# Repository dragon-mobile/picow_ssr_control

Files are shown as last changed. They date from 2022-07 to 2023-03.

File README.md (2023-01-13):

# picow_ssr_control

<br/>



<br/>

The Raspberry Pi Pico W Solid State Relay Controller is primarily meant to be
used with an open hardware solid state relay PCBs that is being co-developed
alongside this project as part of my Dragon Mobile GitHub organization to make
useful hardware with associated firmware and software for the tiny home, van
life and maker communities.

## Visual 3D examples

Top view<br/>
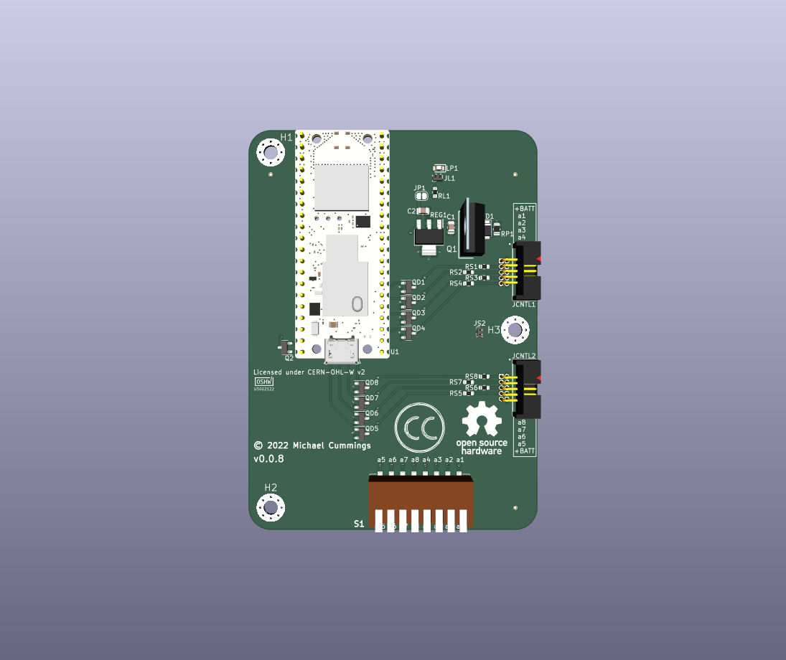
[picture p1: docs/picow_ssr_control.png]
Top view 3D rendering of the circuit board in FreeCAD Circuit board top view
<br/>
Bottom view<br/>
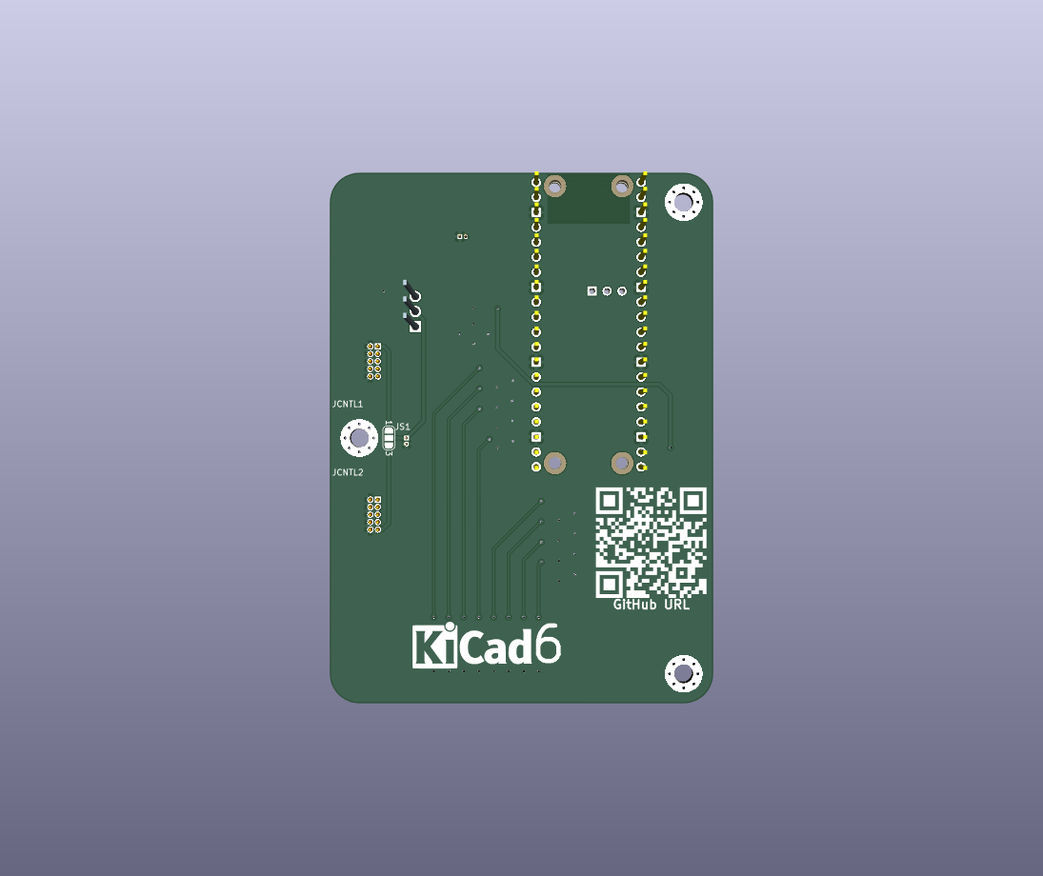
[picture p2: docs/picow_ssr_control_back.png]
Bottom view 3D rendering of the circuit board in FreeCAD Circuit board bottom view
<br/>

## Description

The board consist of four main electronic sections: Power In / Control Out,
Power Management / Regulation, Manual Control,
and the PicoW Control / Drivers.
There is one mechanical section as well: Mounting Holes.

## Contributing

Contributors are welcome.
Please note that this project has a [Contributor Covenant Code of Conduct].
By participating in this project you agree to abide by its terms.

All intentionally contributed hardware will be considered to be contributed
under the [CERN] license without any additional terms or conditions.

All intentionally contributed code will be considered to be contributed
under a [MIT] license without any additional terms or conditions.
Please include your information in a comment on all code files for the copyright
etc.

All intentionally contributed documentation, CAD files and libraries, footprints,
artwork or non-code text like this README etc. will be considered to be
contributed under the same [CC-BY-SA] license without any additional terms or
conditions.

Pull requests are always welcome. For major changes, please open an issue first
to discuss what you would like to change.
Please make sure to update or add tests as appropriate for all software changes.

## Licenses

GitHub<br/>

All hardware is licensed under the

  * [CERN] - CERN-OHL-W-2.0
  
You can find a copy of the CERN Open Hardware License - Weakly-reciprocal v2.0
in the [LICENSE-CERN-OHL-W-2] file and the how-to guide in the
[CERN-HOWTO_GUIDE] file.

All code is licensed under the

  * [MIT] - MIT License

You can find a copy of the license in the [LICENSE-MIT] file.

All documentation like this README is licensed under the Creative Commons
Attribution-ShareAlike 4.0 International License (CC-BY-SA).

All original CAD files and libraries, footprints, and artwork are also licensed
under the
Creative Commons Attribution-ShareAlike 4.0 International License (CC-BY-SA).
You can find a copy of the [CC-BY-SA] license in the [LICENSE-CC-BY-SA] file.

If after reading the above license files, how-tos, and related FAQs on the
linked license sites on how they apply to the project please either open an
issue or contact me (Michael Cummings) via my Github email and I will try
to guided you through my understanding of how it works.

[CC-BY-SA]: http://creativecommons.org/licenses/by-sa/4.0/
[CERN]: https://ohwr.org/project/cernohl/wikis/Documents/CERN-OHL-version-2
[CERN-HOWTO_GUIDE]: docs/cern_ohl_w_v2_howto.pdf
[Contributor Covenant Code of Conduct]: CODE_OF_CONDUCT.md 
[LICENSE-CC-BY-SA]: LICENSE-CC-BY-SA
[LICENSE-CERN-OHL-W-2]: CERN-OHL-W-2
[LICENSE-MIT]: LICENSE-MIT
[MIT]: https://opensource.org/licenses/MIT

<hr>
Copyright &copy; 2022-2023, Michael Cummings<br/>
<a rel="license" href="http://creativecommons.org/licenses/by-sa/4.0/">

</a>

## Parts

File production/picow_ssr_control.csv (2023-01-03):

Id | Designator | Package | Quantity | Designation | Supplier and ref
1 | REG1 | SOT230P700X180-4N | 1 | LM7805
2 | JS2,JL1 | PinHeader_1x02_P1.00mm_Vertical | 2 | Conn_01x02
3 | RS4,RS7,RS1,RS5,RS2,RL1,RS6,RS8,RS3 | R_0603_1608Metric | 9 | 270
4 | QD8,QD2,QD1,QD6,QD4,QD3,QD5,QD7 | SOT-23 | 8 | 2N7002K
5 | JCNTL2,JCNTL1 | SAMTEC_SHF-105-01-L-D-RA | 2 | SHF-105-01-L-D-RA
6 | Q2 | DMG2301L | 1 | DMG2301L
7 | C2 | C_0805_2012Metric | 1 | 100n
8 | S1 | 1938MS | 1 | 193-8MS
9 | RP1 | R_0805_2012Metric | 1 | 100k
10 | C1 | C_0805_2012Metric | 1 | 330n
11 | Q1 | TO254P469X1042X1967-3P | 1 | IRF4905PBF
12 | ZD1 | BZD27C10P-M3-08 | 1 | +10v Zener Diode
13 | LP1 | LEDC1608X80N | 1 | LTST-C190KGKT
14 | U1 | Raspberry_Pi_Pico_THT | 1 | RaspberryPi-PicoW

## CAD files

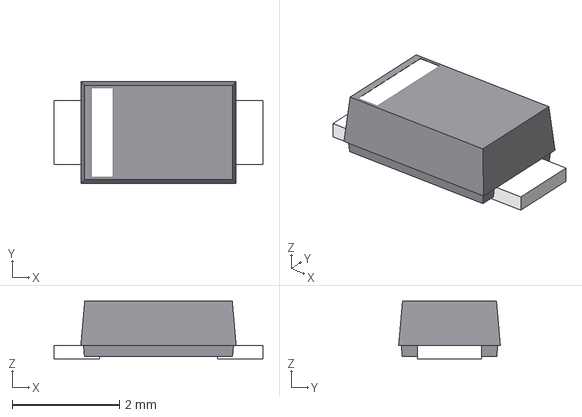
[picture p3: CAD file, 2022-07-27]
hardware/picow_ssr_control/3dmodels/BZD27C10P-M3-08.stp
3.90 x 1.90 x 1.08 mm

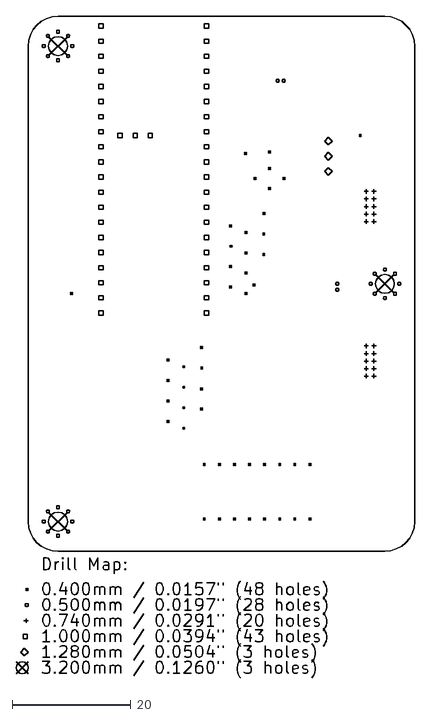
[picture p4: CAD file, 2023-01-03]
production/picow_ssr_control-PTH-drl_map.dxf
67.0 x 111.3

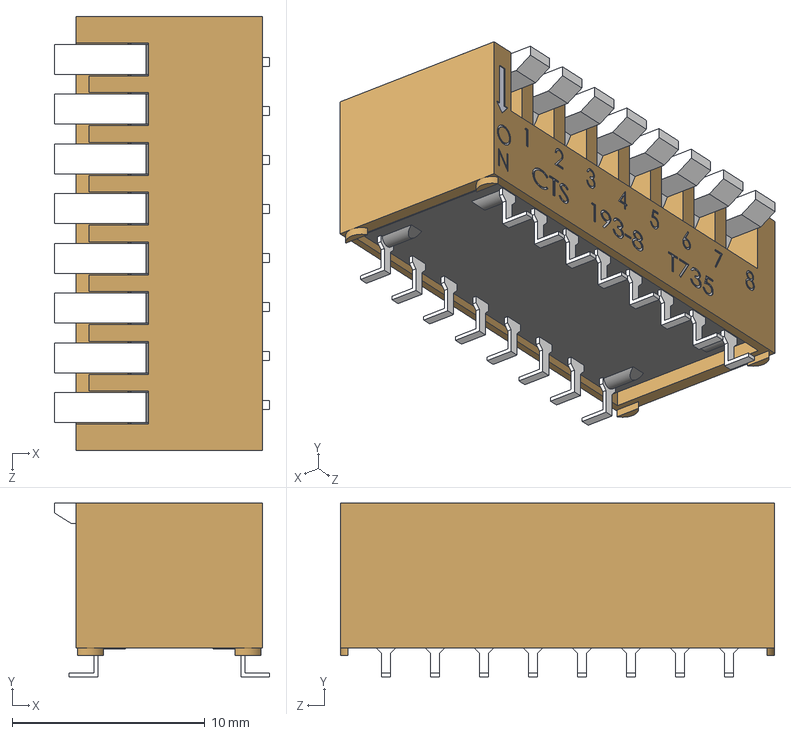
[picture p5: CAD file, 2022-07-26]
hardware/picow_ssr_control/3dmodels/193-8MS.STEP
11.2 x 9.02 x 22.5 mm
193-8 pole assembly

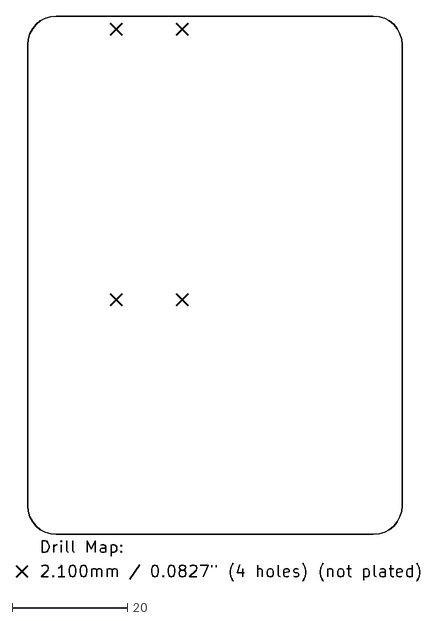
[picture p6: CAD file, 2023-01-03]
production/picow_ssr_control-NPTH-drl_map.dxf
70.1 x 98.1

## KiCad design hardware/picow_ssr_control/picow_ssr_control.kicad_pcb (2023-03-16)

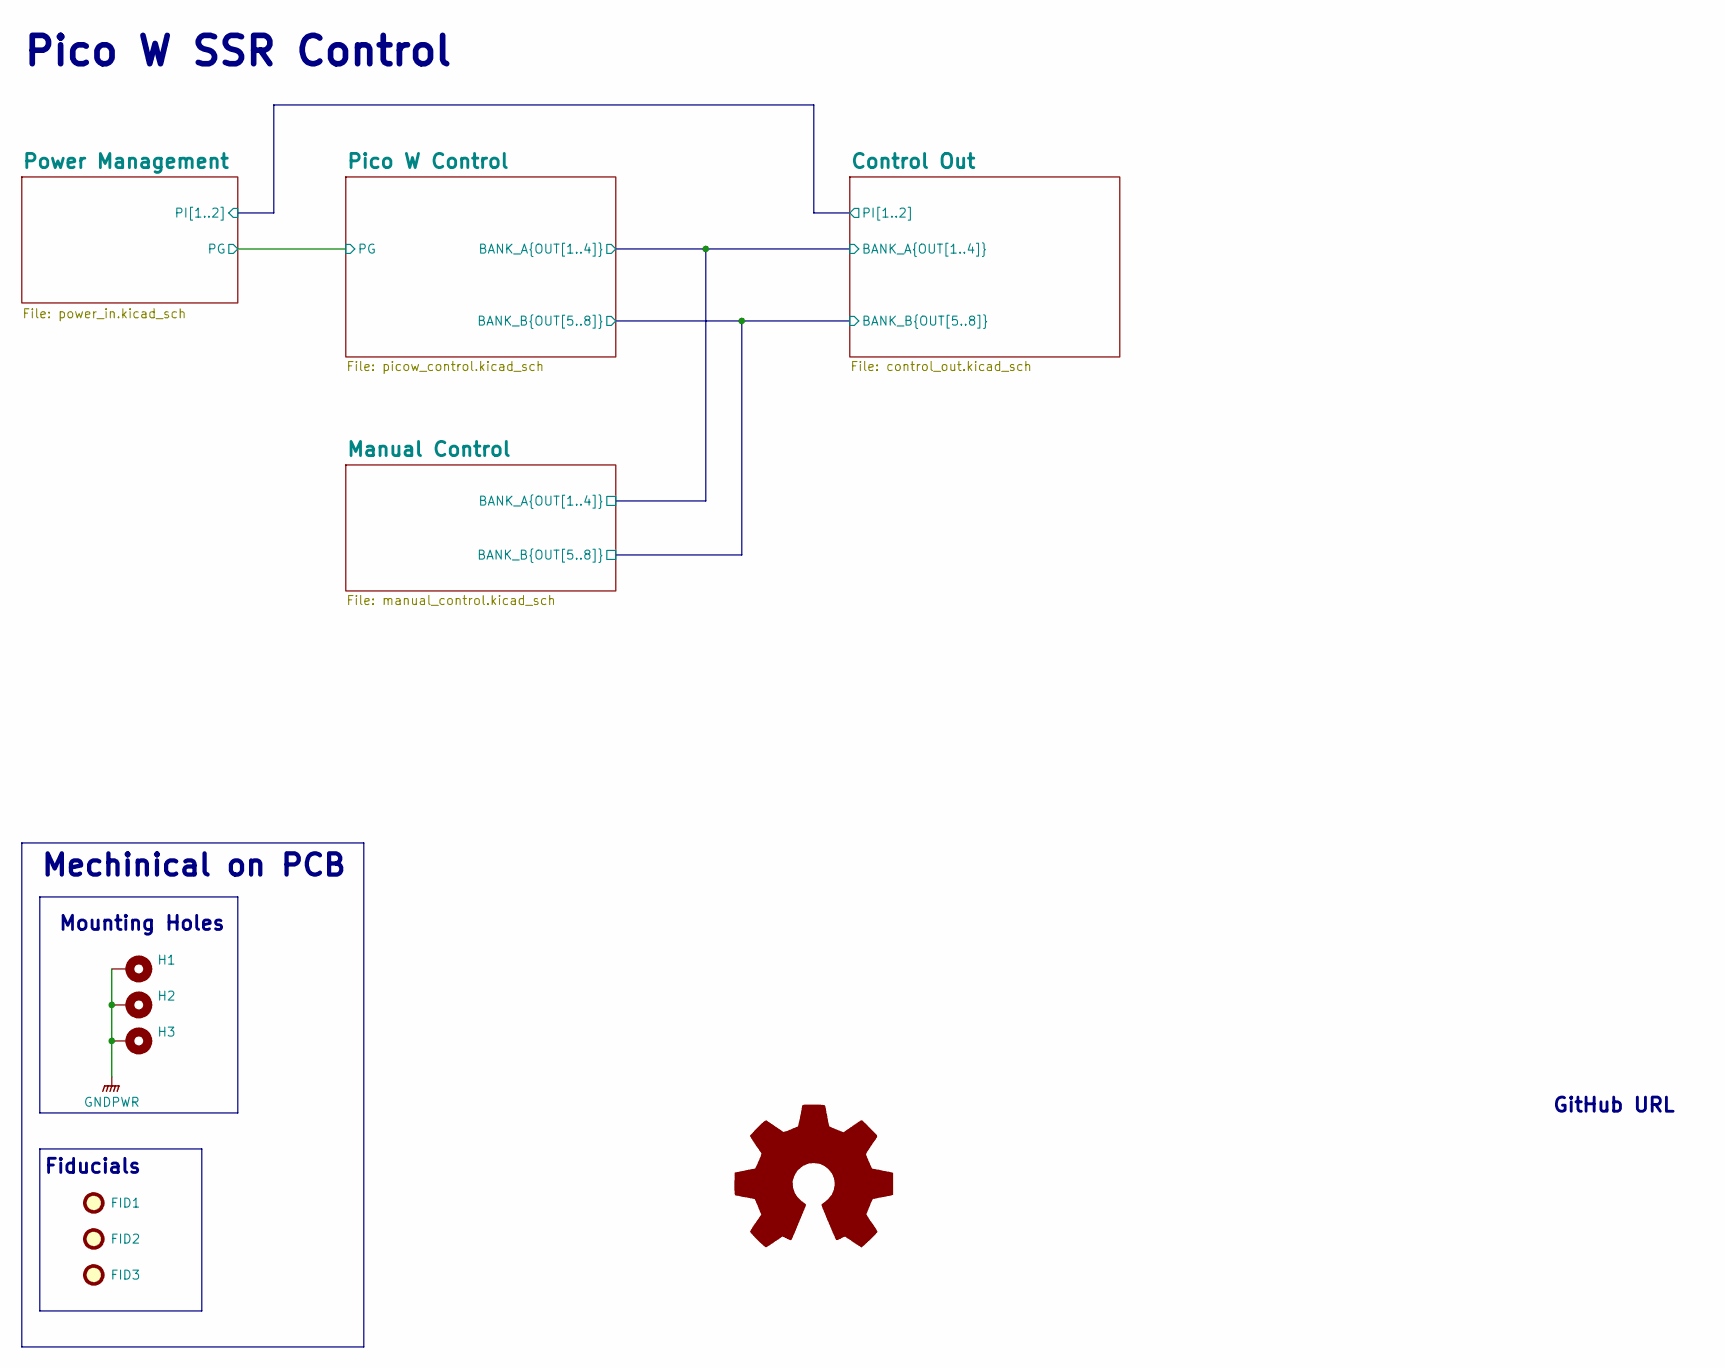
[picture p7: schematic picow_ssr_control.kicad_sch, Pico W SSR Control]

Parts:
FID1, FID2, FID3: Fiducial; Fiducial_0.5mm_Mask1mm
H1, H2, H3: MountingHole_Pad; MountingHole_3.2mm_M3_Pad_Via

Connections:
GNDPWR: H1.1, H2.1, H3.1; also elsewhere on the board

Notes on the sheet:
${TITLE}
Mounting Holes
GitHub URL
Mechinical on PCB
Fiducials

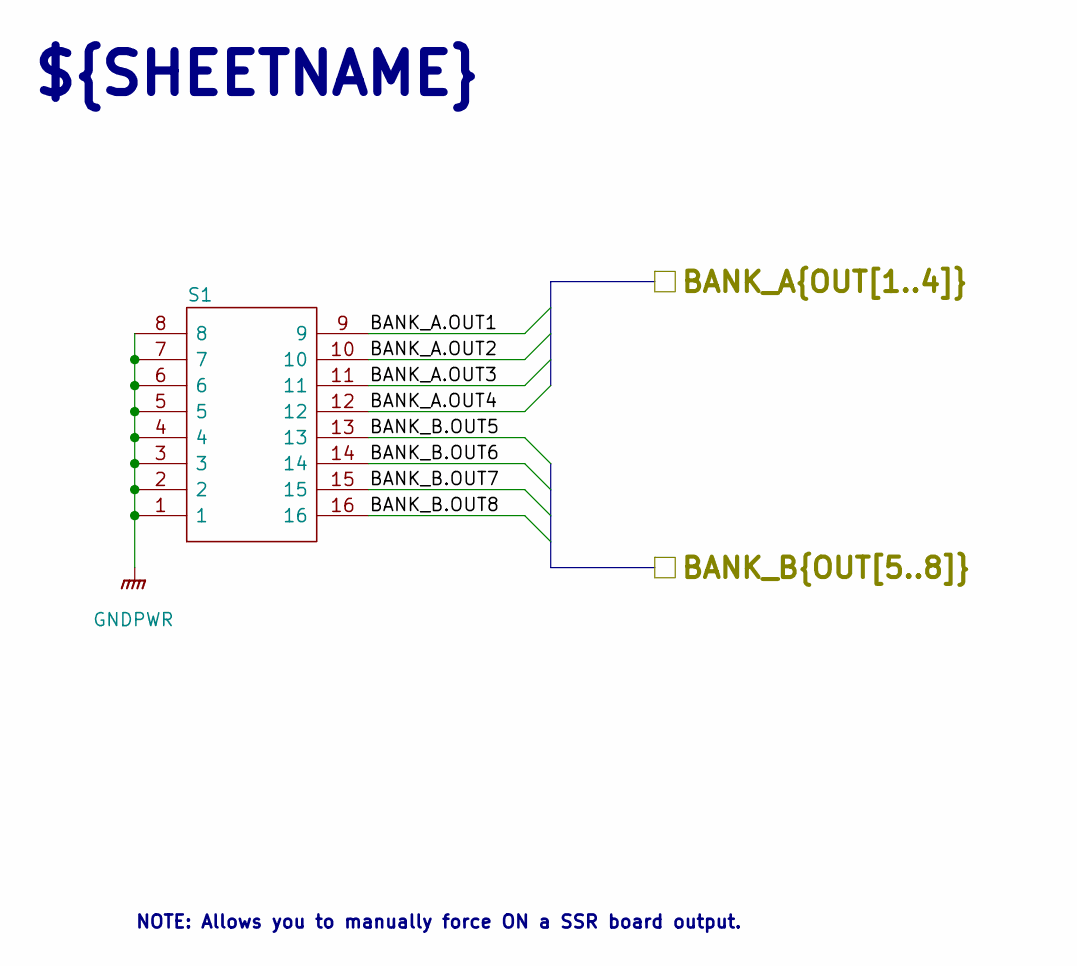
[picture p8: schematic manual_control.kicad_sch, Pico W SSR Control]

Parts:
S1: 193-8MS; 1938MS; Mouser Part Number 774-1938MS

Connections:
/Control Out/BANK_A.OUT1: S1.9; also elsewhere on the board
/Control Out/BANK_A.OUT2: S1.10; also elsewhere on the board
/Control Out/BANK_A.OUT3: S1.11; also elsewhere on the board
/Control Out/BANK_A.OUT4: S1.12; also elsewhere on the board
/Control Out/BANK_B.OUT5: S1.13; also elsewhere on the board
/Control Out/BANK_B.OUT6: S1.14; also elsewhere on the board
/Control Out/BANK_B.OUT7: S1.15; also elsewhere on the board
/Control Out/BANK_B.OUT8: S1.16; also elsewhere on the board
GNDPWR: S1.1, S1.2, S1.3, S1.4, S1.5, S1.6, S1.7, S1.8; also elsewhere on the board

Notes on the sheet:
${SHEETNAME}
NOTE: Allows you to manually force ON a SSR board output.

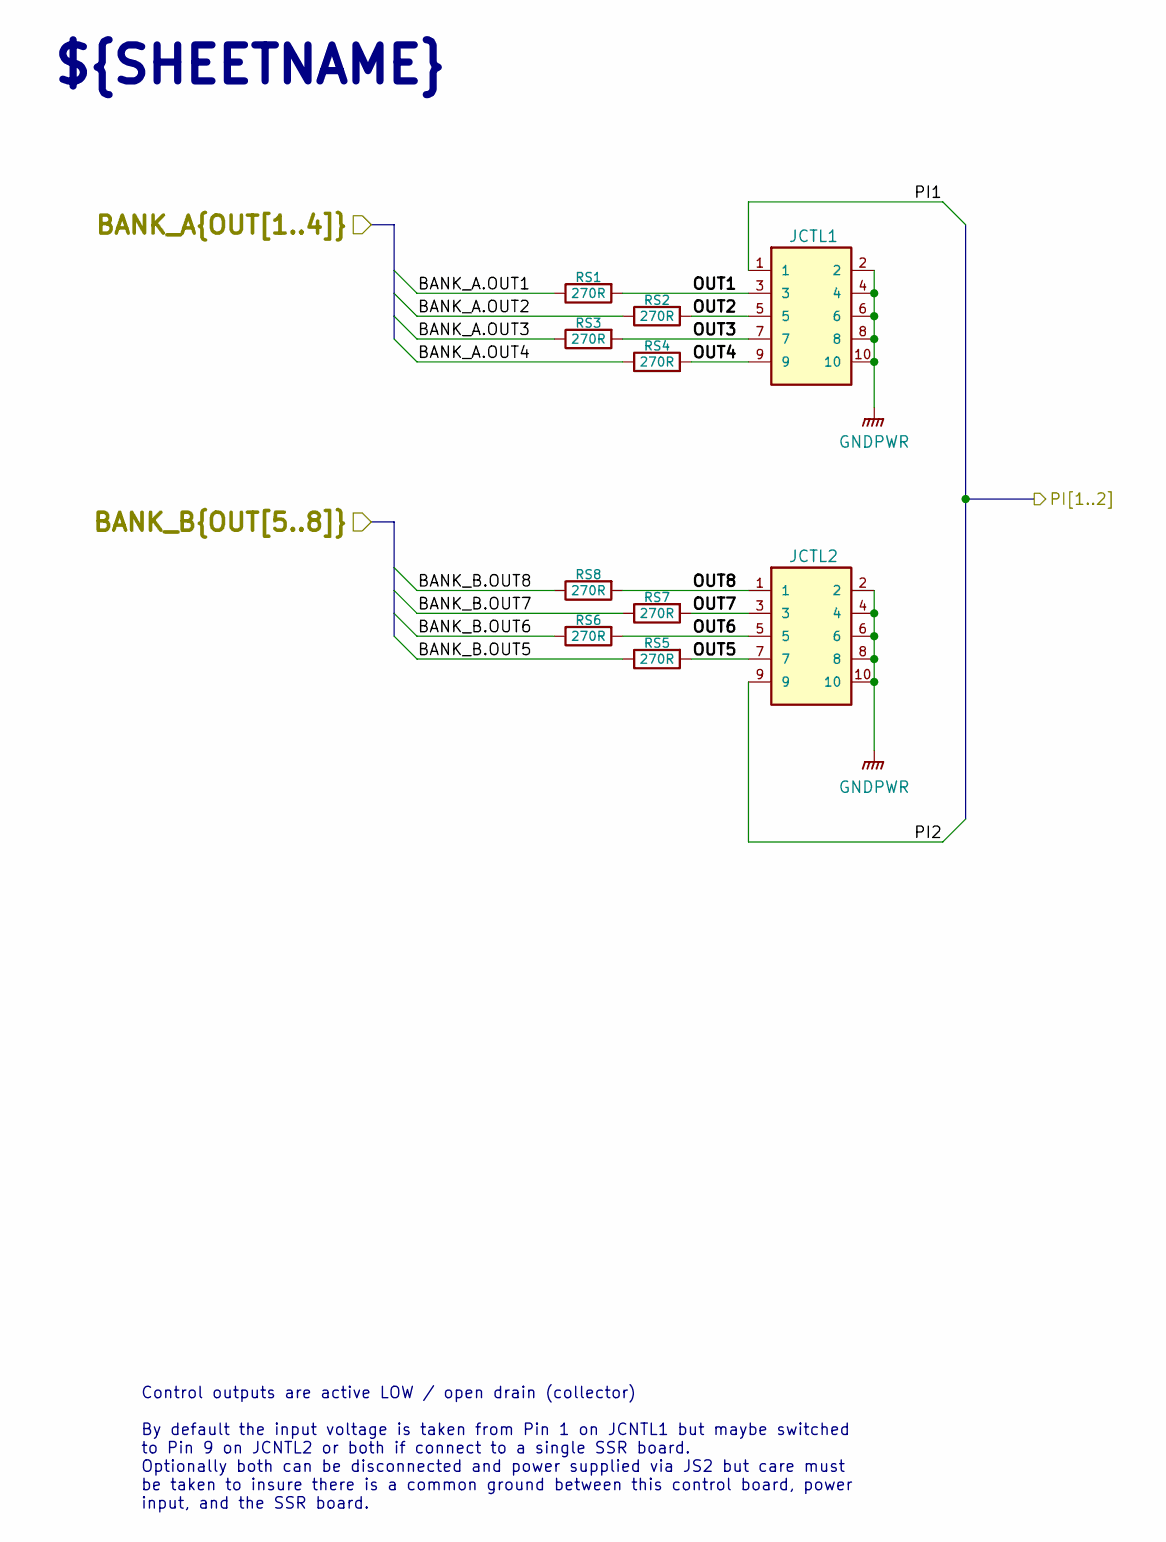
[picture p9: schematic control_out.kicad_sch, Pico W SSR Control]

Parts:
JCTL1, JCTL2: SHF-105-01-L-D-RA; SAMTEC_SHF-105-01-L-D-RA; Mouser Part Number 200-SHF10501LDRATR
RS1, RS2, RS3, RS4, RS5, RS6, RS7, RS8: 270R; R_0603_1608Metric; Mouser Part Number 755-SDR03EZPJ271

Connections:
/Control Out/BANK_A.OUT1: RS1.1; also elsewhere on the board
/Control Out/BANK_A.OUT2: RS2.1; also elsewhere on the board
/Control Out/BANK_A.OUT3: RS3.1; also elsewhere on the board
/Control Out/BANK_A.OUT4: RS4.1; also elsewhere on the board
/Control Out/BANK_B.OUT5: RS5.1; also elsewhere on the board
/Control Out/BANK_B.OUT6: RS6.1; also elsewhere on the board
/Control Out/BANK_B.OUT7: RS7.1; also elsewhere on the board
/Control Out/BANK_B.OUT8: RS8.1; also elsewhere on the board
/Control Out/OUT1: JCTL1.3, RS1.2
/Control Out/OUT2: JCTL1.5, RS2.2
/Control Out/OUT3: JCTL1.7, RS3.2
/Control Out/OUT4: JCTL1.9, RS4.2
/Control Out/OUT5: JCTL2.7, RS5.2
/Control Out/OUT6: JCTL2.5, RS6.2
/Control Out/OUT7: JCTL2.3, RS7.2
/Control Out/OUT8: JCTL2.1, RS8.2
/Control Out/PI1: JCTL1.1; also elsewhere on the board
/Control Out/PI2: JCTL2.9; also elsewhere on the board
GNDPWR: JCTL1.2, JCTL1.4, JCTL1.6, JCTL1.8, JCTL1.10, JCTL2.2, JCTL2.4, JCTL2.6, JCTL2.8, JCTL2.10; also elsewhere on the board

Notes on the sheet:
Control outputs are active LOW / open drain (collector) By default the input voltage is taken from Pin 1 on JCNTL1 but maybe switched to Pin 9 on JCNTL2 or both if connect to a single SSR board. Optionally both can be disconnected and power supplied via JS2 but care must be taken to insure there is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
${SHEETNAME}

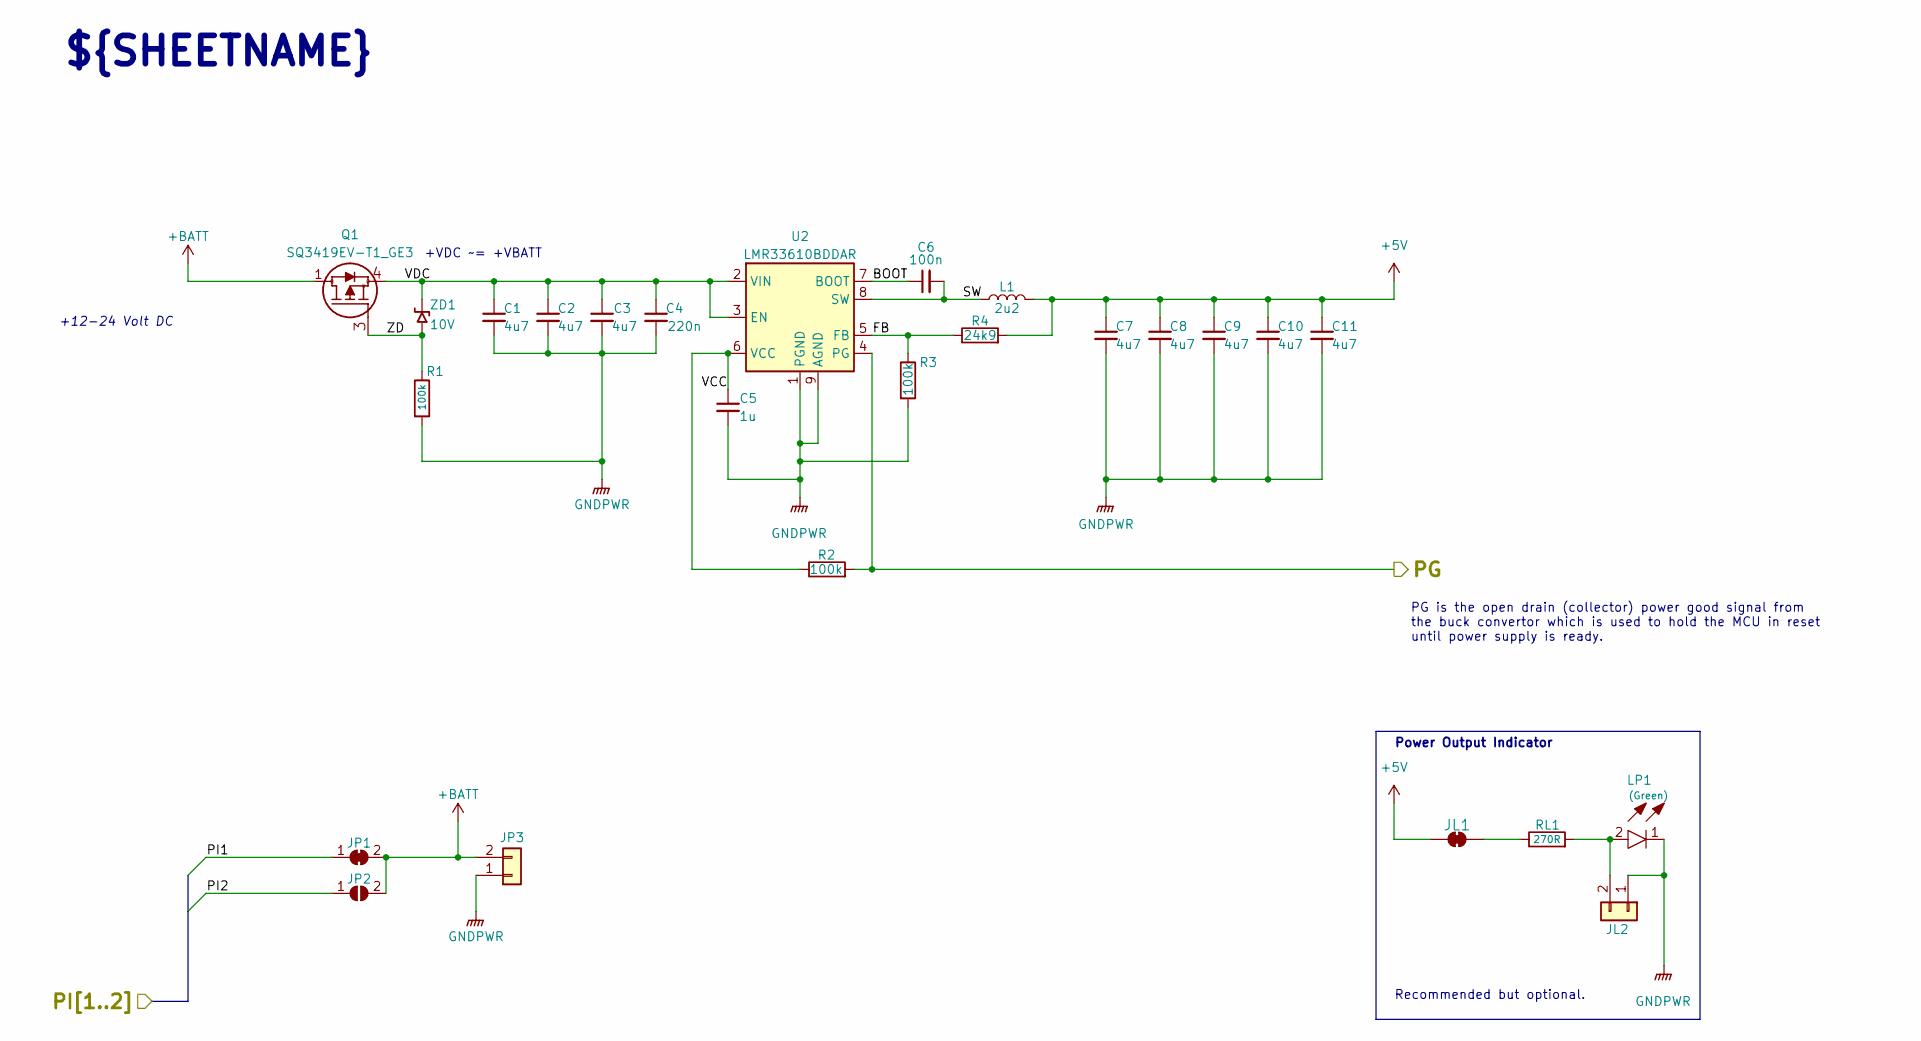
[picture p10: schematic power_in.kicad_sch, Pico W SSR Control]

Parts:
C1, C2, C3, C7, C8, C9, C10, C11: 4u7; C_0805_2012Metric; Mouser Part Number 810-CGA4J1X7R1H475K1
C4: 220n; C_0603_1608Metric; Mouser Part Number 810-CGA3E3X7R1H224K
C5: 1u; C_0603_1608Metric; Mouser Part Number 810-CGA3E3X5R1H105K
C6: 100n; C_0603_1608Metric; Mouser Part Number 810-CGA3E2X7R1H104K
JL1: SolderJumper_2_Bridged; SolderJumper-2_P1.3mm_Bridged_RoundedPad1.0x1.5mm
JL2: Conn_01x02; PinHeader_1x02_P1.00mm_Vertical
JP1: SolderJumper_2_Bridged; SolderJumper-2_P1.3mm_Bridged_RoundedPad1.0x1.5mm
JP2: SolderJumper_2_Open; SolderJumper-2_P1.3mm_Open_RoundedPad1.0x1.5mm
JP3: Conn_01x02; PinHeader_1x02_P1.00mm_Vertical
L1: 2u2; L_1008_2520Metric; Mouser Part Number 810-TFM252012ALVA2R2
LP1: LTST-C190KGKT; LEDC1608X80N; Mouser Part Number 859-LTST-C190KGKT
Q1: SQ3419EV-T1_GE3; SOT95P284X110-6N; Mouser Part Number 78-SQ3419EV-T1_GE3
R1, R2, R3: 100k; R_0603_1608Metric; Mouser Part Number 667-ERJ-PA3F1003V
R4: 24k9; R_0603_1608Metric; Mouser Part Number 667-ERJ-PA3F2492V
RL1: 270R; R_0603_1608Metric; Mouser Part Number 755-SDR03EZPJ271
U2: LMR33610BDDAR; Texas_HSOP-8-1EP_3.9x4.9mm_P1.27mm_ThermalVias; Mouser Part Number 595-LMR33610BDDAR
ZD1: 10V; D_0805_2012Metric; Mouser Part Number 821-BZY55B10RBG

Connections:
+5V: C7.1, C8.1, C9.1, C10.1, C11.1, JL1.1 (A), L1.2, R4.2; also elsewhere on the board
+BATT: JP1.2 (B), JP2.2 (B), JP3.2, Q1.1 (D), Q1.2 (D), Q1.5 (D), Q1.6 (D)
/Control Out/PI1: JP1.1 (A); also elsewhere on the board
/Control Out/PI2: JP2.1 (A); also elsewhere on the board
/Pico W Control/PG: R2.2, U2.4 (PG); also elsewhere on the board
/Power Management/BOOT: C6.1, U2.7 (BOOT)
/Power Management/FB: R3.1, R4.1, U2.5 (FB)
/Power Management/SW: C6.2, L1.1, U2.8 (SW)
/Power Management/VCC: C5.1, R2.1, U2.6 (VCC)
/Power Management/VDC: C1.1, C2.1, C3.1, C4.1, Q1.4 (S), U2.2 (VIN), U2.3 (EN), ZD1.1
/Power Management/ZD: Q1.3 (G), R1.1, ZD1.2
GNDPWR: C1.2, C2.2, C3.2, C4.2, C5.2, C7.2, C8.2, C9.2, C10.2, C11.2, JL2.1, JP3.1, LP1.1, R1.2, R3.2, U2.1 (PGND), U2.9 (AGND); also elsewhere on the board
unnamed: JL1.2 (B), RL1.1
unnamed: JL2.2, LP1.2, RL1.2

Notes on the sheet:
+VDC ~= +VBATT
+12-24 Volt DC
Recommended but optional.
Power Output Indicator
PG is the open drain (collector) power good signal from the buck convertor which is used to hold the MCU in reset until power supply is ready.
${SHEETNAME}

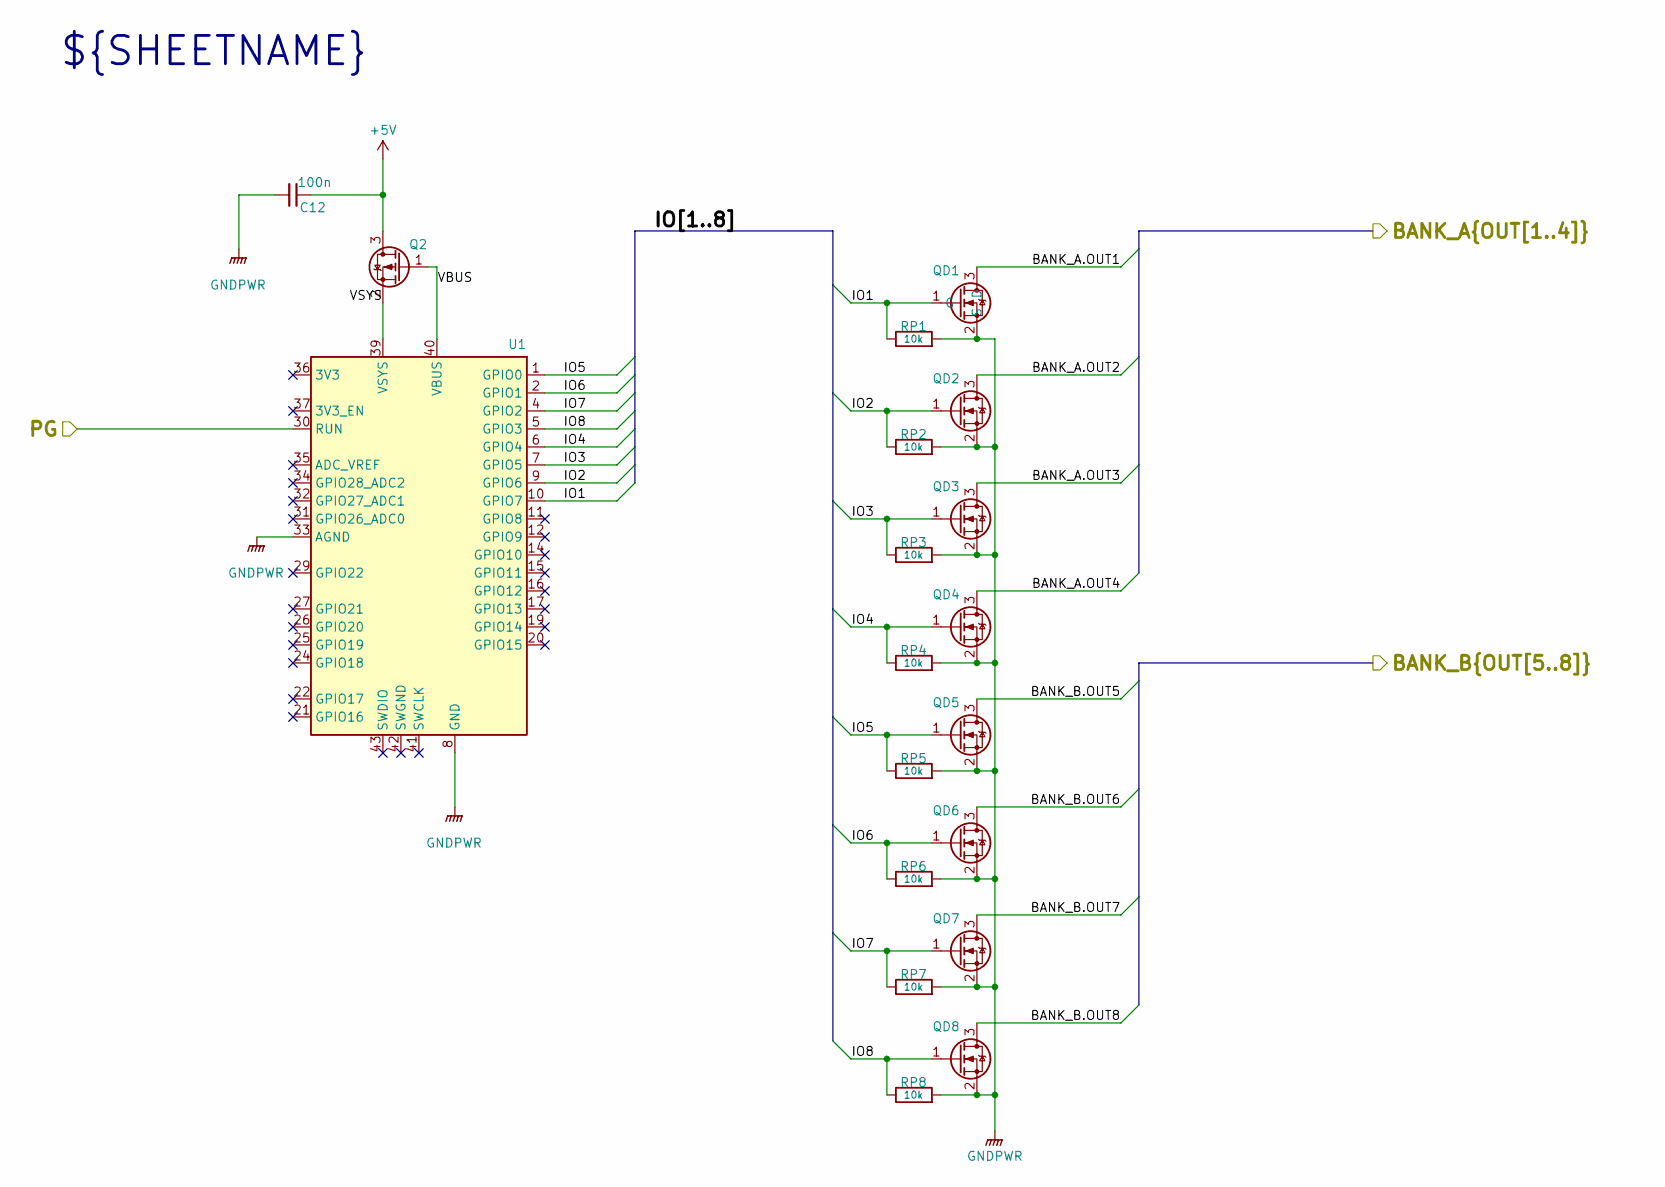
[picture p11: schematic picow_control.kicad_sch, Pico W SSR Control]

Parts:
C12: 100n; C_0603_1608Metric; Mouser Part Number 810-CGA3E2X7R1H104K
Q2: DMG2305UX-7; SOT-23; Mouser Part Number 621-DMG2305UX-7
QD1, QD2, QD3, QD4, QD5, QD6, QD7, QD8: 2N7002K; 2V7002KT1G; Mouser Part Number 863-2V7002KT1G
RP1, RP2, RP3, RP4, RP5, RP6, RP7, RP8: 10k; R_0603_1608Metric; Mouser Part Number 755-SDR03EZPJ103
U1: RaspberryPi-PicoW; Raspberry_Pi_Pico_THT

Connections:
+5V: C12.1, Q2.3 (D); also elsewhere on the board
/Control Out/BANK_A.OUT1: QD1.3 (D); also elsewhere on the board
/Control Out/BANK_A.OUT2: QD2.3 (D); also elsewhere on the board
/Control Out/BANK_A.OUT3: QD3.3 (D); also elsewhere on the board
/Control Out/BANK_A.OUT4: QD4.3 (D); also elsewhere on the board
/Control Out/BANK_B.OUT5: QD5.3 (D); also elsewhere on the board
/Control Out/BANK_B.OUT6: QD6.3 (D); also elsewhere on the board
/Control Out/BANK_B.OUT7: QD7.3 (D); also elsewhere on the board
/Control Out/BANK_B.OUT8: QD8.3 (D); also elsewhere on the board
/Pico W Control/IO1: QD1.1 (G), RP1.1, U1.10 (GPIO7)
/Pico W Control/IO2: QD2.1 (G), RP2.1, U1.9 (GPIO6)
/Pico W Control/IO3: QD3.1 (G), RP3.1, U1.7 (GPIO5)
/Pico W Control/IO4: QD4.1 (G), RP4.1, U1.6 (GPIO4)
/Pico W Control/IO5: QD5.1 (G), RP5.1, U1.1 (GPIO0)
/Pico W Control/IO6: QD6.1 (G), RP6.1, U1.2 (GPIO1)
/Pico W Control/IO7: QD7.1 (G), RP7.1, U1.4 (GPIO2)
/Pico W Control/IO8: QD8.1 (G), RP8.1, U1.5 (GPIO3)
/Pico W Control/PG: U1.30 (RUN); also elsewhere on the board
/Pico W Control/VBUS: Q2.1 (G), U1.40 (VBUS)
/Pico W Control/VSYS: Q2.2 (S), U1.39 (VSYS)
GNDPWR: C12.2, QD1.2 (S), QD2.2 (S), QD3.2 (S), QD4.2 (S), QD5.2 (S), QD6.2 (S), QD7.2 (S), QD8.2 (S), RP1.2, RP2.2, RP3.2, RP4.2, RP5.2, RP6.2, RP7.2, RP8.2, U1.3 (GND), U1.8 (GND), U1.13 (GND), U1.18 (GND), U1.23 (GND), U1.28 (GND), U1.33 (AGND), U1.38 (GND); also elsewhere on the board

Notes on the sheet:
${SHEETNAME}

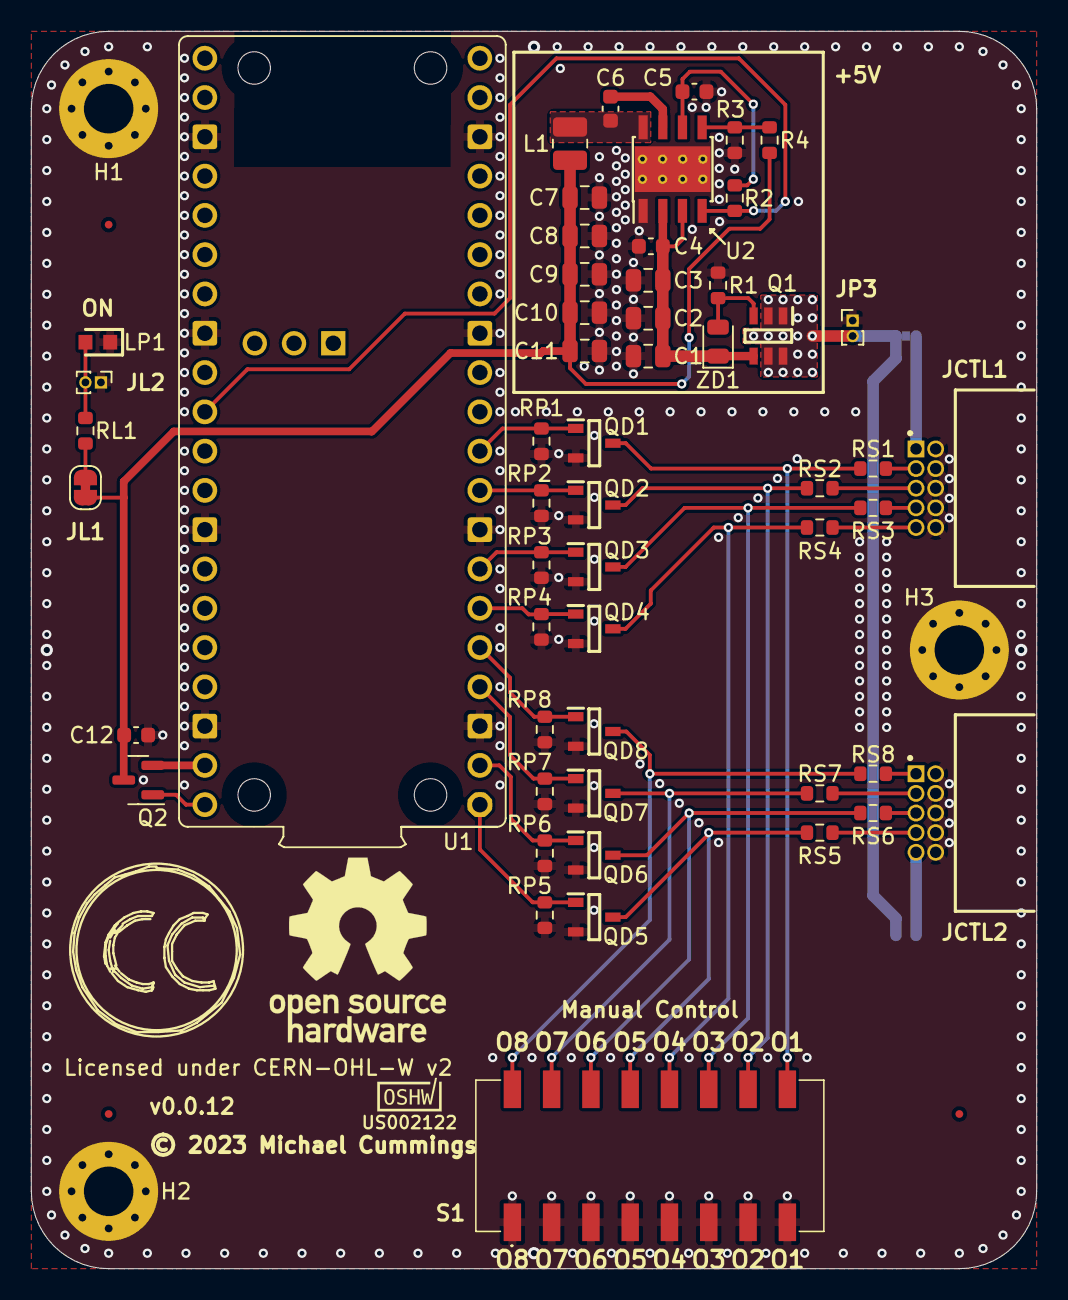
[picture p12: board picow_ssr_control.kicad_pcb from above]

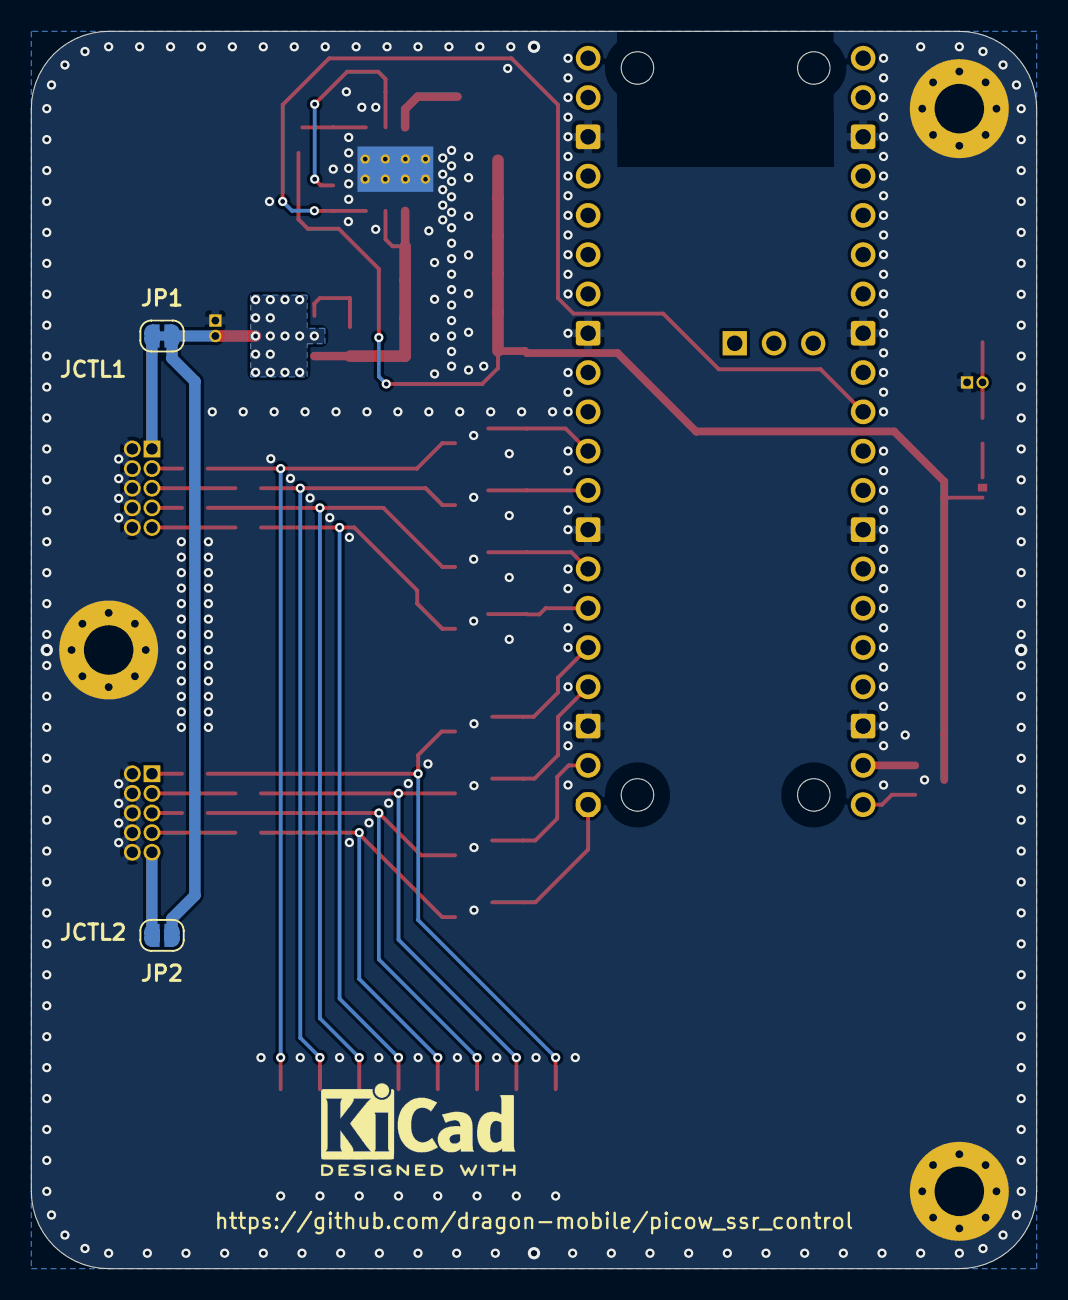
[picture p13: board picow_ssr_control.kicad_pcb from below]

Board: 2 copper layers, 65.0 x 80.0 mm, 66 parts (3 on the bottom side), 40 nets.

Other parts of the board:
JCNTL1_Label: JCNTL1_Label
JCNTL2_Label: JCNTL2_Label
OSHW_Mono_0.1_Scale: ${COMMENT5}; OSHW_Mono_0.1_Scale
REF_KiCAD: KiCad-Logo2_5mm_SilkScreen

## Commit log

2022-07-26 Added project symbols, footprints etc.
    [193-8MS.STEP, picow_ssr_control.kicad_pcb, picow_ssr_control.kicad_sch]
2022-07-26 Added Copyright and logos etc.
    [picow_ssr_control.kicad_pcb, picow_ssr_control.kicad_sch]
2022-07-27 Added Updated symbol, footprint, 3d model for zener diode
    [BZD27C10P-M3-08.stp, picow_ssr_control.kicad_pcb, picow_ssr_control.kicad_sch]
2022-07-27 Adding first couple badges to README.md
2022-08-06 Add new Cern licensing info
    [picow_ssr_control.kicad_pcb, picow_ssr_control.kicad_sch]
2022-08-06 Synced up schema and PCB versions and Licensing silkscreening
    [picow_ssr_control.kicad_pcb, picow_ssr_control.kicad_sch]
2022-08-06 Fixed incorrect copyright date on PCB
    [picow_ssr_control.kicad_pcb]
2022-12-08 WIP control connector changes v0.0.7
    [picow_ssr_control.kicad_pcb, picow_ssr_control.kicad_sch]
2022-12-22 Replaced un-obtainable ULN2803 with SMD FETs and updated control connectors
    [picow_ssr_control.kicad_pcb, picow_ssr_control.kicad_sch]
2023-01-02 Misc minor updates after tag
    [picow_ssr_control.kicad_pcb, picow_ssr_control.kicad_sch]
2023-01-03 Vertical Pico, Moved connectors, and draft production files
    [picow_ssr_control-B_Cu.gbr, picow_ssr_control-B_Mask.gbr, picow_ssr_control-B_Paste.gbr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]
2023-01-13 Added front & back PCB pics and start of desc. to README.md
2023-01-24 Added pulldowns to driver FETs and realigned control connectors and other components
    [picow_ssr_control.kicad_pcb, picow_ssr_control.kicad_sch]
2023-01-28 Changed schematic to hierarchical style with mutliple sheets
    [control_out.kicad_sch, manual_control.kicad_sch, picow_control.kicad_sch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]
2023-02-05 Updated schemas
    [control_out.kicad_sch, manual_control.kicad_sch, picow_control.kicad_sch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]
2023-02-08 Power supply changes plus misc.
    [control_out.kicad_sch, manual_control.kicad_sch, picow_control.kicad_sch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]
2023-02-13 Pre KiCad 7.0.0 WIP
    [control_out.kicad_sch, manual_control.kicad_sch, picow_control.kicad_sch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]
2023-03-13 Commit before trying changes to power system
    [control_out.kicad_sch, manual_control.kicad_sch, picow_control.kicad_sch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]
2023-03-16 Commit before removing git submodule
    [control_out.kicad_sch, manual_control.kicad_sch, picow_control.kicad_sch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]

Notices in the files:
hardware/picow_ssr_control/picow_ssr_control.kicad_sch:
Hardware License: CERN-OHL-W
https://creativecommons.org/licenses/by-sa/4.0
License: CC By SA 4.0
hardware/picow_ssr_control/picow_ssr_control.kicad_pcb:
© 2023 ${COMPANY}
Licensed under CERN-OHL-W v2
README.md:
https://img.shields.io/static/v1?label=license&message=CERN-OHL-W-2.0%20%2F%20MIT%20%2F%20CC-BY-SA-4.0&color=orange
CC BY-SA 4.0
